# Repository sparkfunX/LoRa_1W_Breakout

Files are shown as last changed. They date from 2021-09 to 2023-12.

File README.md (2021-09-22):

SparkFun LoRa 1W Breakout
========================================

SparkFun LoRa 1W Breakout (https://www.sparkfun.com/products/18572)

[*SparkFun LoRa 1W Breakout (SPX-18572)*](https://www.sparkfun.com/products/18572)

Do you need power? This breakout for the 915M30S module from EBYTE is a 1W (30dB) LoRa transceiver. LoRa is great for long range long range (miles), low power (in sleep), and low data rates (~500bps). This breakout board is designed to connect to any platform that has SPI and 6 available GPIO. We include a robust edge mount RP-SMA connector to connect large LoRa (915MHz) antennas. In addition, the on-board U.FL connector can be used if you need to get outside a metal enclosure. 

We've successfully broadcast 12 miles line-of-sight (thank you [foothills](https://www.google.com/search?q=boulder+foothills&tbm=isch)!) using this module but your results may vary.

Our example sketches make quick work of the initial setup for the [SX1276 LoRa transceiver](https://www.semtech.com/products/wireless-rf/lora-core/sx1276) from Semtech, and the RadioLib Arduino Library makes advanced configuration and [protocols](https://github.com/jgromes/RadioLib/wiki/Default-configuration#protocols) (AX.25, Hellschreiber, Morse, RTTY, and SSTV) a cinch too!

Repository Contents
-------------------

* **/Documents** - Datasheets and mechanical drawings
* **/Hardware** - All Eagle design files (.brd, .sch, .STL)

Product Versions
----------------

* [SPX-18572](https://www.sparkfun.com/products/18572)

License Information
-------------------

This product is _**open source**_! 

Please review the LICENSE.md file for license information. 

If you have any questions or concerns on licensing, please contact technical support on our [SparkFun forums](https://forum.sparkfun.com/viewforum.php?f=152).

Distributed as-is; no warranty is given.

- Your friends at SparkFun.

_<COLLABORATION CREDIT>_

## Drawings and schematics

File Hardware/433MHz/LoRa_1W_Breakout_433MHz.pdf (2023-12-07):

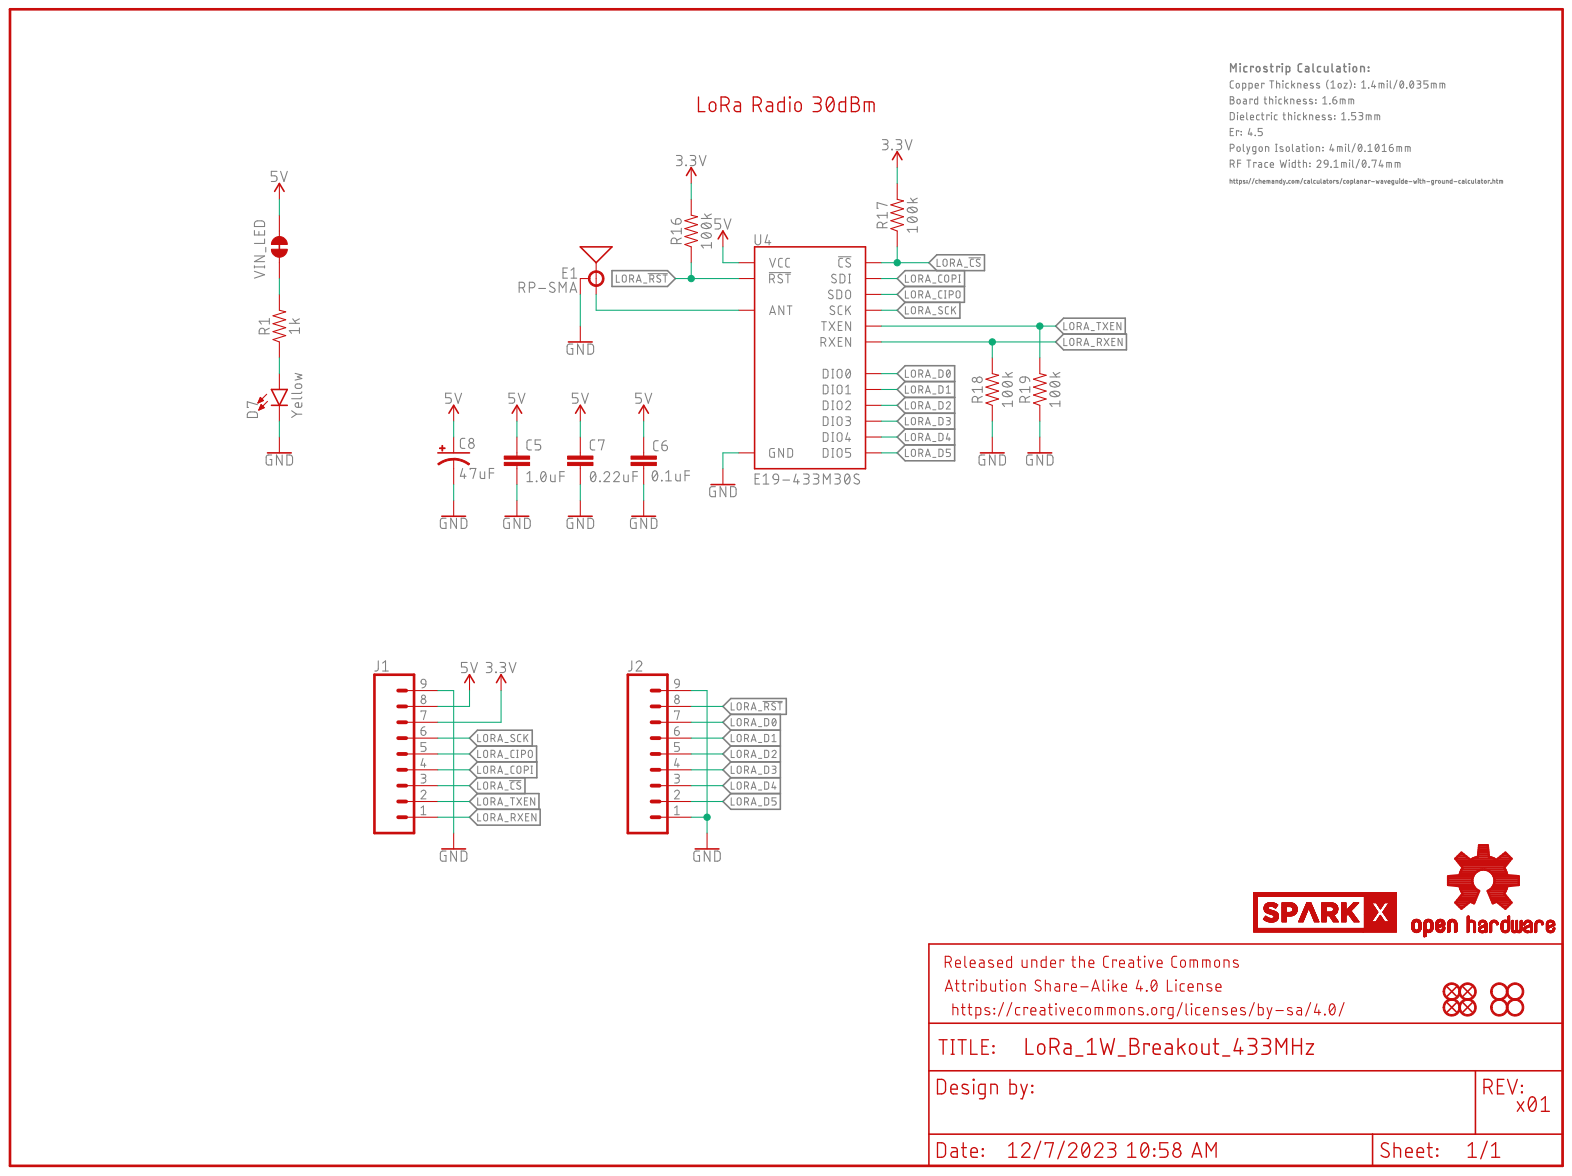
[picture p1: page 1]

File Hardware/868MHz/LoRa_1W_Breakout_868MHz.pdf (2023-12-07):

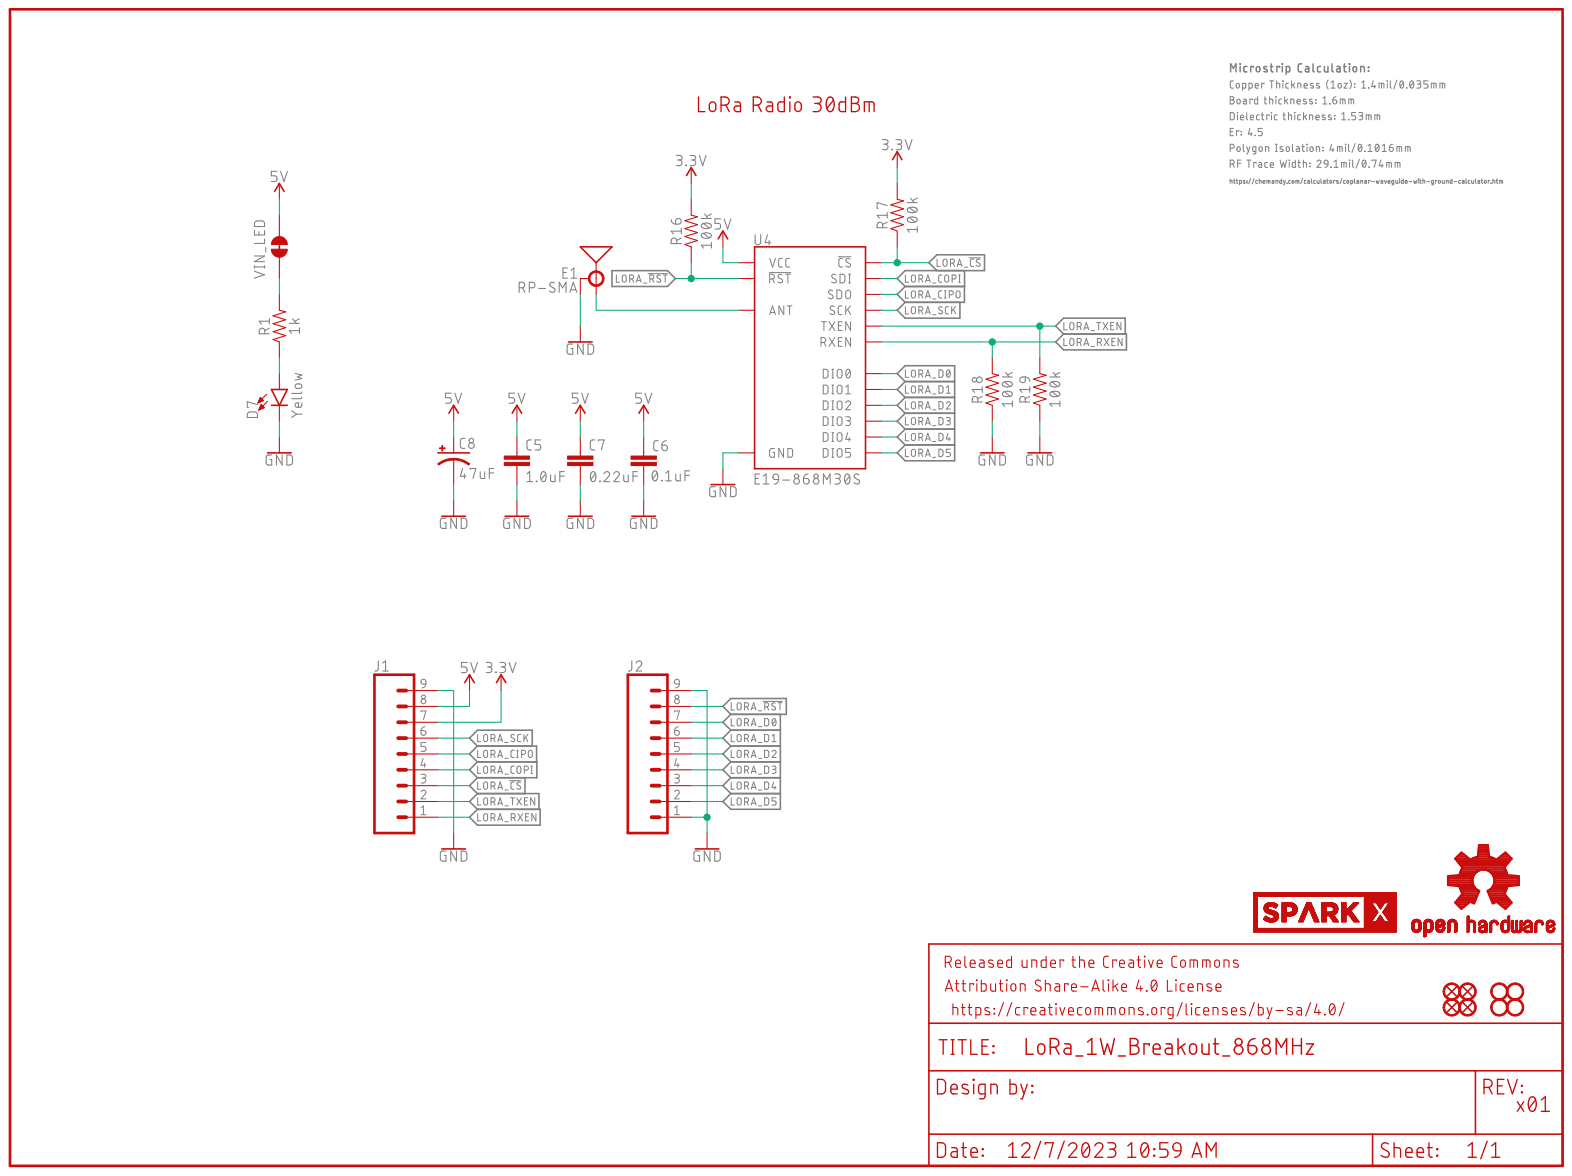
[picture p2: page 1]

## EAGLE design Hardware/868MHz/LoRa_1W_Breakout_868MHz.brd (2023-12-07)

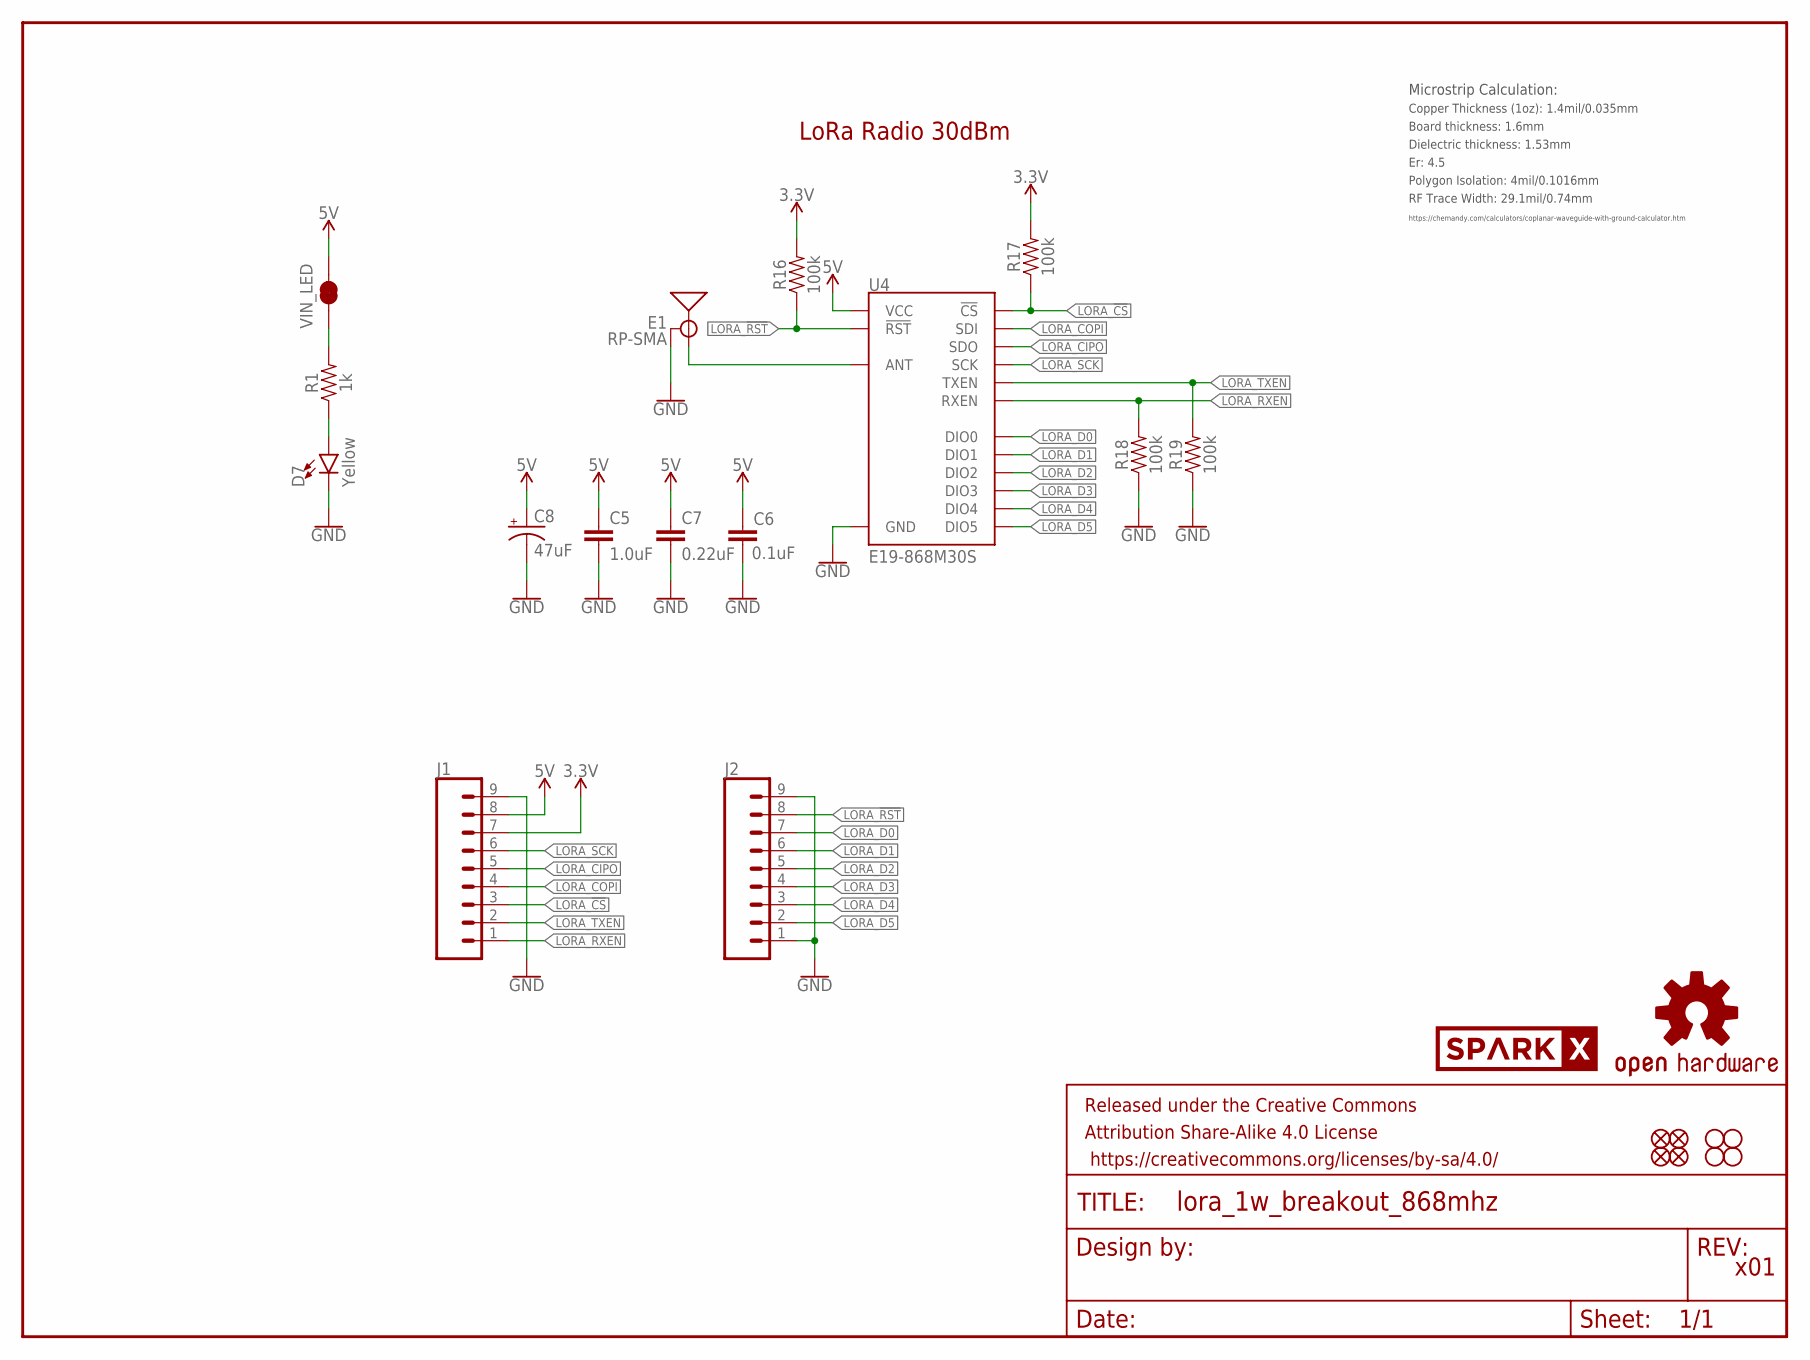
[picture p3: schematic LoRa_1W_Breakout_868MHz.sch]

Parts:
C5: 1.0uF; 0603
C6: 0.1uF; 0603
C7: 0.22uF; 0603
C8: 47uF; EIA3528
D7: Yellow; LED-0603
E1: RP-SMA; SMA-EDGE
FD1, FD2, FD3, FD4: FIDUCIALUFIDUCIAL; FIDUCIAL-MICRO
FRAME2: FRAME-LETTER; CREATIVE_COMMONS
H1, H2, H3, H4: STAND-OFF
J1, J2: CONN_09NO_SILK; 1X09_NO_SILK
LOGO3: OSHW-LOGOMINI; OSHW-LOGO-MINI
R1: 1k; 0603
R16, R17, R18, R19: 100k; 0603
U4: E19-868M30S; E19-915M30S
U$5: SPARKX-LOGO5; SPARKX-LARGE
VIN_LED: JUMPER-SMT_2_NC_TRACE_SILK; SMT-JUMPER_2_NC_TRACE_SILK

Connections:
3.3V: J1.7, R16.2, R17.2
5V: C5.1, C6.1, C7.1, C8.A (+), J1.8, U4.11 (VCC), VIN_LED.2
GND: C5.2, C6.2, C7.2, C8.C (-), D7.C, E1.GND@0 (GND), E1.GND@1 (GND), E1.GND@2 (GND), E1.GND@3 (GND), J1.9, J2.1, J2.9, R18.1, R19.1, U4.1 (GND), U4.9 (GND), U4.10 (GND), U4.18 (GND), U4.20 (GND), U4.21 (GND), U4.22 (GND)
LORA_!CS!: J1.3, R17.1, U4.15 (!CS)
LORA_!RST!: J2.8, R16.1, U4.8 (!RST)
LORA_CIPO: J1.5, U4.13 (SDO)
LORA_COPI: J1.4, U4.14 (SDI)
LORA_D0: J2.7, U4.7 (DIO0)
LORA_D1: J2.6, U4.6 (DIO1)
LORA_D2: J2.5, U4.5 (DIO2)
LORA_D3: J2.4, U4.4 (DIO3)
LORA_D4: J2.3, U4.3 (DIO4)
LORA_D5: J2.2, U4.2 (DIO5)
LORA_RF: E1.SIG (SIGNAL), U4.19 (ANT)
LORA_RXEN: J1.1, R18.2, U4.17 (RXEN)
LORA_SCK: J1.6, U4.12 (SCK)
LORA_TXEN: J1.2, R19.2, U4.16 (TXEN)
unnamed: R1.2, VIN_LED.1
unnamed: D7.A, R1.1

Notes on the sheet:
x01
LoRa Radio 30dBm
Board thickness: 1.6mm
Er: 4.5
Copper Thickness (1oz): 1.4mil/0.035mm
RF Trace Width: 29.1mil/0.74mm
Polygon Isolation: 4mil/0.1016mm
Dielectric thickness: 1.53mm
https://chemandy.com/calculators/coplanar-waveguide-with-ground-calculator.htm
Microstrip Calculation:

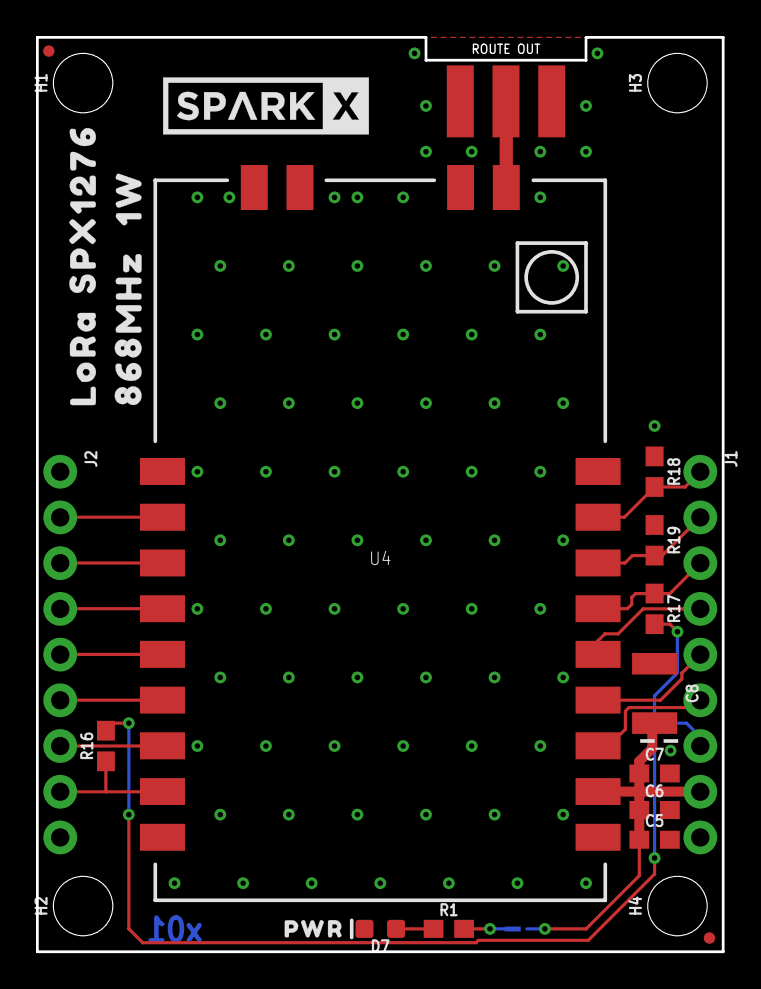
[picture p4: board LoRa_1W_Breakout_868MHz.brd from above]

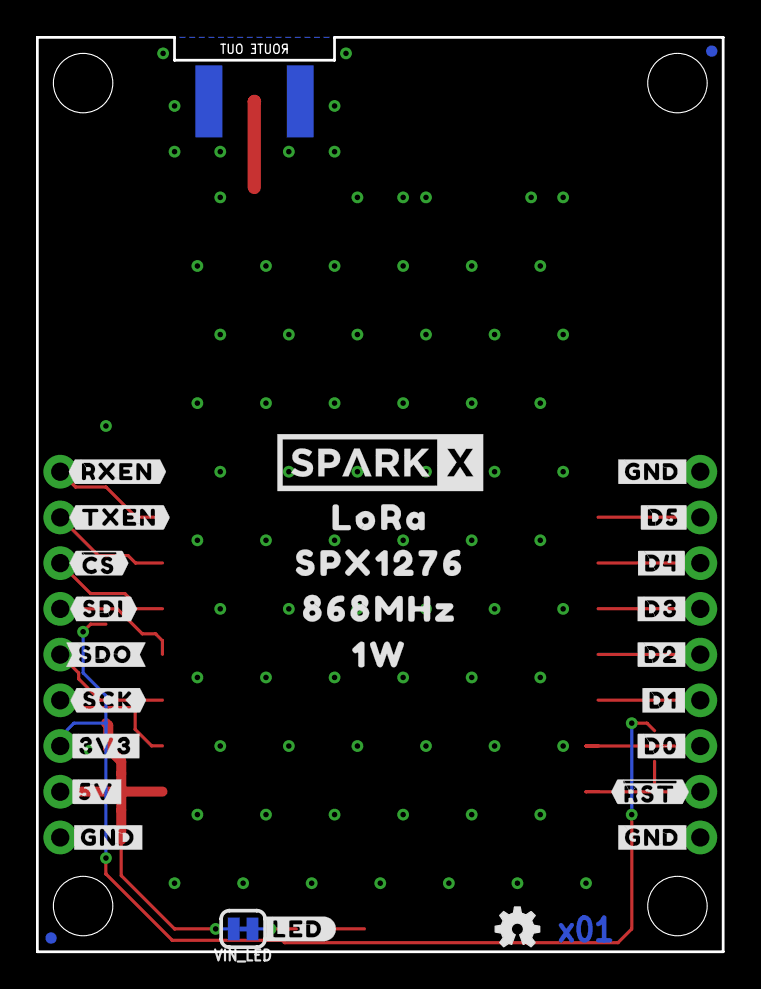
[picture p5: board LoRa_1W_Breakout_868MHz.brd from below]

Board: 2 copper layers, 38.1 x 50.8 mm, 55 parts (28 on the bottom side), 19 nets.

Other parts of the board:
U$1, U$67: LORA0
U$2, U$69: SPX12760
U$3, U$27: 1W1
U$4: PWR0
U$6: SPARKX-LOGO5; SPARKX-LARGE
U$7, U$9: 868MHZ0
U$15: #LED#0
U$43: #5V#1
U$44: #3V3#0
U$45: #SDO#3
U$46: #SDI#4
U$47: ##CS##5
U$48: #TXEN#6
U$49: #RXEN#7
U$52, U$53, U$61: #GND#8
U$54: #D5#6
U$55: #D4#5
U$56: #D3#4
U$57: #D2#3
U$58: #D1#2
U$59: #D0#1
U$60: ##RST##0
U$62: #SCK#2

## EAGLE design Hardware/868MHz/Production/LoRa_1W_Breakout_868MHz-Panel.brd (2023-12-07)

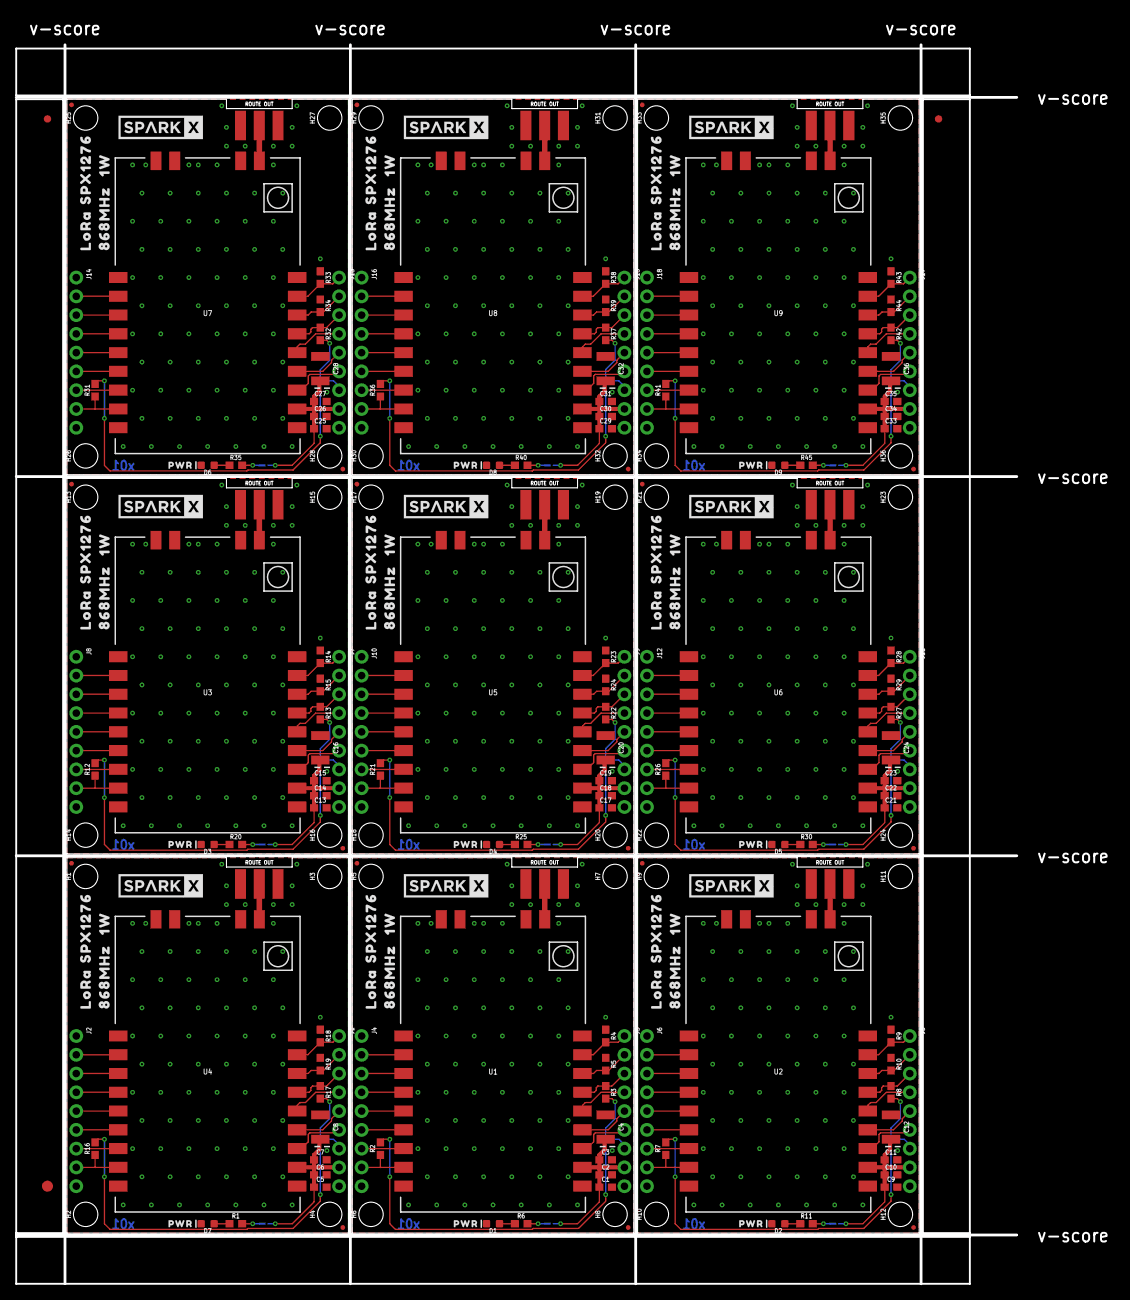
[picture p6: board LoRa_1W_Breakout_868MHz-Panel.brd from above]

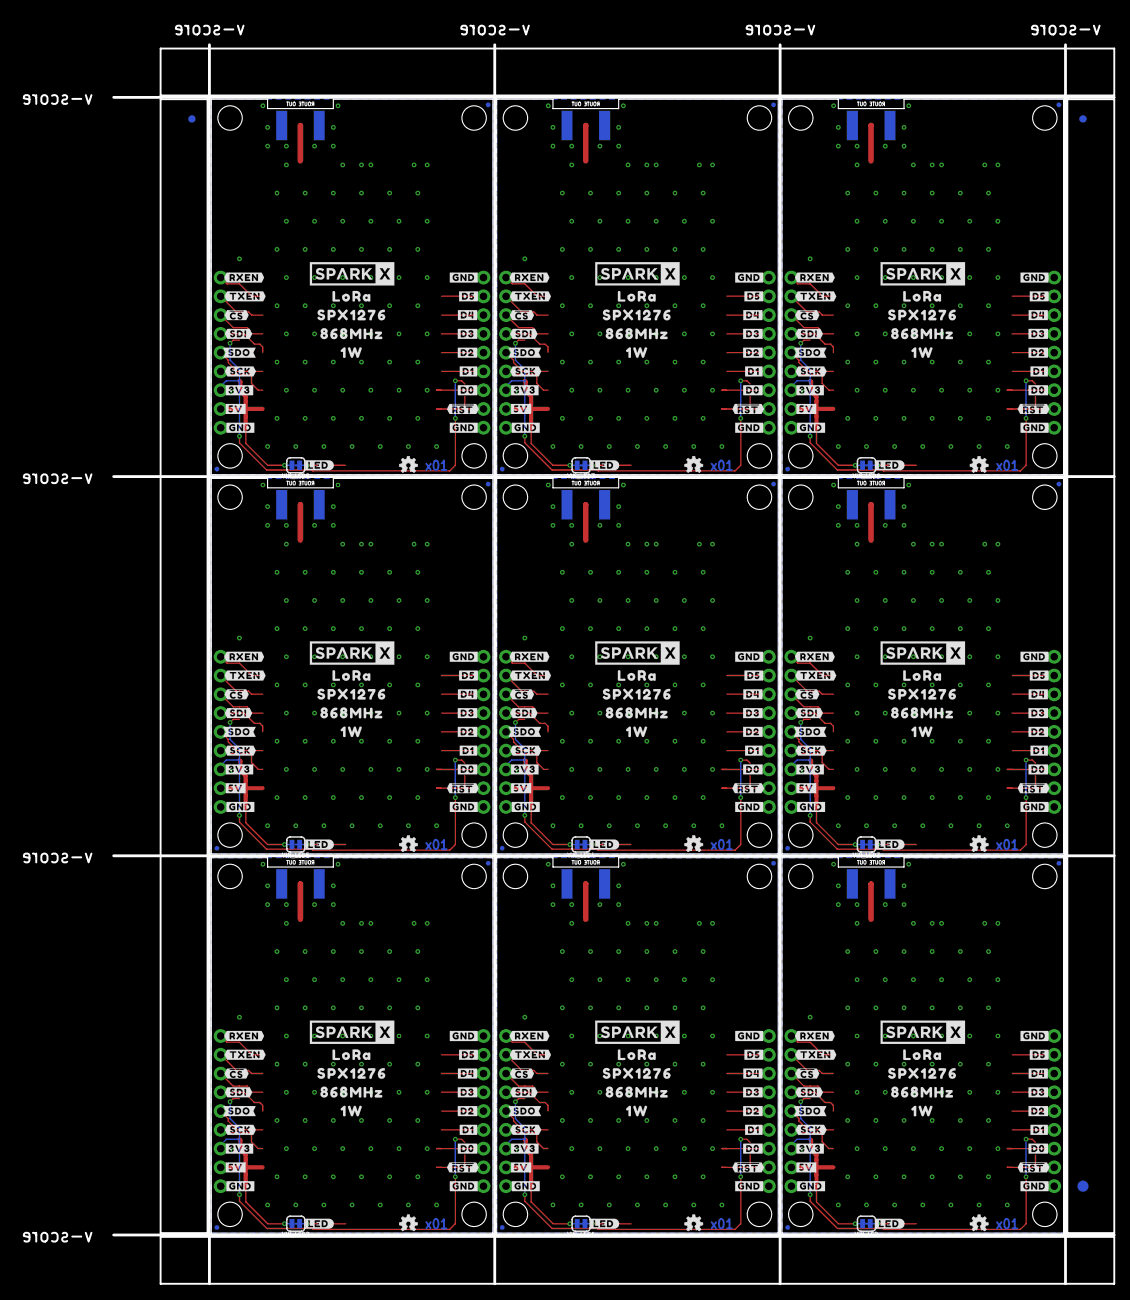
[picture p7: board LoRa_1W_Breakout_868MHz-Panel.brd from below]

Board: 2 copper layers, 135.4 x 167.6 mm, 492 parts (255 on the bottom side), 171 nets.

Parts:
C1, C5, C9, C13, C17, C21, C25, C29, C33: 1.0uF; 0603
C2, C6, C10, C14, C18, C22, C26, C30, C34: 0.1uF; 0603
C3, C7, C11, C15, C19, C23, C27, C31, C35: 0.22uF; 0603
C4, C8, C12, C16, C20, C24, C28, C32, C36: 47uF; EIA3528
D1, D2, D3, D4, D5, D6, D7, D8, D9: Yellow; LED-0603
E1, E2, E3, E4, E5, E6, E7, E8, E9: RP-SMA; SMA-EDGE
E$1, E$2, E$3, E$4: FIDUCIAL-1X2
E$5, E$6: FIDUCIAL-1.5X3
FD1, FD2, FD3, FD4, FD5, FD6, FD7, FD8, FD9, FD10, FD11, FD12, FD13, FD14, FD15, FD16, FD17, FD18, FD19, FD20, FD21, FD22, FD23, FD24, FD25, FD26, FD27, FD28, FD29, FD30, FD31, FD32, FD33, FD34, FD35, FD36: FIDUCIALUFIDUCIAL; FIDUCIAL-MICRO
H1, H2, H3, H4, H5, H6, H7, H8, H9, H10, H11, H12, H13, H14, H15, H16, H17, H18, H19, H20, H21, H22, H23, H24, H25, H26, H27, H28, H29, H30, H31, H32, H33, H34, H35, H36: STAND-OFF
J1, J2, J3, J4, J5, J6, J7, J8, J9, J10, J11, J12, J13, J14, J15, J16, J17, J18: 1X09_NO_SILK
LOGO1, LOGO2, LOGO3, LOGO4, LOGO5, LOGO6, LOGO7, LOGO8, LOGO9: OSHW-LOGOMINI; OSHW-LOGO-MINI
R1, R6, R11, R20, R25, R30, R35, R40, R45: 1k; 0603
R2, R3, R4, R5, R7, R8, R9, R10, R12, R13, R14, R15, R16, R17, R18, R19, R21, R22, R23, R24, R26, R27, R28, R29, R31, R32, R33, R34, R36, R37, R38, R39, R41, R42, R43, R44: 100k; 0603
U1, U2, U3, U4, U5, U6, U7, U8, U9: E19-915M30S
U$1, U$32, U$34, U$67, U$82, U$84, U$112, U$114, U$142, U$144, U$172, U$174, U$202, U$204, U$232, U$234, U$262, U$264: LORA0
U$2, U$33, U$35, U$69, U$83, U$85, U$113, U$115, U$143, U$145, U$173, U$175, U$203, U$205, U$233, U$235, U$263, U$265: SPX12760
U$3, U$27, U$31, U$36, U$81, U$86, U$111, U$116, U$141, U$146, U$171, U$176, U$201, U$206, U$231, U$236, U$261, U$266: 1W1
U$4, U$8, U$41, U$91, U$121, U$151, U$181, U$211, U$241: PWR0
U$5, U$6, U$37, U$38, U$87, U$88, U$117, U$118, U$147, U$148, U$177, U$178, U$207, U$208, U$237, U$238, U$267, U$268: SPARKX-LOGO5; SPARKX-LARGE
U$7, U$9, U$39, U$40, U$89, U$90, U$119, U$120, U$149, U$150, U$179, U$180, U$209, U$210, U$239, U$240, U$269, U$270: 868MHZ0
U$10, U$15, U$42, U$92, U$122, U$152, U$182, U$212, U$242: #LED#0
U$11, U$43, U$50, U$93, U$123, U$153, U$183, U$213, U$243: #5V#1
U$12, U$44, U$51, U$94, U$124, U$154, U$184, U$214, U$244: #3V3#0
U$13, U$45, U$63, U$95, U$125, U$155, U$185, U$215, U$245: #SDO#3
U$14, U$46, U$64, U$96, U$126, U$156, U$186, U$216, U$246: #SDI#4
U$16, U$47, U$65, U$97, U$127, U$157, U$187, U$217, U$247: ##CS##5
U$17, U$48, U$66, U$98, U$128, U$158, U$188, U$218, U$248: #TXEN#6
U$18, U$49, U$68, U$99, U$129, U$159, U$189, U$219, U$249: #RXEN#7
U$19, U$20, U$29, U$52, U$53, U$61, U$70, U$71, U$79, U$100, U$101, U$109, U$130, U$131, U$139, U$160, U$161, U$169, U$190, U$191, U$199, U$220, U$221, U$229, U$250, U$251, U$259: #GND#8
U$21, U$54, U$72, U$102, U$132, U$162, U$192, U$222, U$252: #D5#6
U$22, U$55, U$73, U$103, U$133, U$163, U$193, U$223, U$253: #D4#5
U$23, U$56, U$74, U$104, U$134, U$164, U$194, U$224, U$254: #D3#4
U$24, U$57, U$75, U$105, U$135, U$165, U$195, U$225, U$255: #D2#3
U$25, U$58, U$76, U$106, U$136, U$166, U$196, U$226, U$256: #D1#2
U$26, U$59, U$77, U$107, U$137, U$167, U$197, U$227, U$257: #D0#1
U$28, U$60, U$78, U$108, U$138, U$168, U$198, U$228, U$258: ##RST##0
U$30, U$62, U$80, U$110, U$140, U$170, U$200, U$230, U$260: #SCK#2
VIN_LED, VIN_LED1, VIN_LED2, VIN_LED3, VIN_LED4, VIN_LED5, VIN_LED6, VIN_LED7, VIN_LED8: JUMPER-SMT_2_NC_TRACE_SILK; SMT-JUMPER_2_NC_TRACE_SILK

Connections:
3.3V: J1.7, R16.2, R17.2
3.3V1: J3.7, R2.2, R3.2
3.3V2: J5.7, R7.2, R8.2
3.3V3: J7.7, R12.2, R13.2
3.3V4: J9.7, R21.2, R22.2
3.3V5: J11.7, R26.2, R27.2
3.3V6: J13.7, R31.2, R32.2
3.3V7: J15.7, R36.2, R37.2
3.3V8: J17.7, R41.2, R42.2
5V: C5.1, C6.1, C7.1, C8.A, J1.8, U4.11, VIN_LED.2
5V1: C1.1, C2.1, C3.1, C4.A, J3.8, U1.11, VIN_LED1.2
5V2: C9.1, C10.1, C11.1, C12.A, J5.8, U2.11, VIN_LED2.2
5V3: C13.1, C14.1, C15.1, C16.A, J7.8, U3.11, VIN_LED3.2
5V4: C17.1, C18.1, C19.1, C20.A, J9.8, U5.11, VIN_LED4.2
5V5: C21.1, C22.1, C23.1, C24.A, J11.8, U6.11, VIN_LED5.2
5V6: C25.1, C26.1, C27.1, C28.A, J13.8, U7.11, VIN_LED6.2
5V7: C29.1, C30.1, C31.1, C32.A, J15.8, U8.11, VIN_LED7.2
5V8: C33.1, C34.1, C35.1, C36.A, J17.8, U9.11, VIN_LED8.2
GND: C5.2, C6.2, C7.2, C8.C, D7.C, E1.GND@0, E1.GND@1, E1.GND@2, E1.GND@3, J1.9, J2.1, J2.9, R18.1, R19.1, U4.1, U4.9, U4.10, U4.18, U4.20, U4.21, U4.22
GND1: C1.2, C2.2, C3.2, C4.C, D1.C, E2.GND@0, E2.GND@1, E2.GND@2, E2.GND@3, J3.9, J4.1, J4.9, R4.1, R5.1, U1.1, U1.9, U1.10, U1.18, U1.20, U1.21, U1.22
GND2: C9.2, C10.2, C11.2, C12.C, D2.C, E3.GND@0, E3.GND@1, E3.GND@2, E3.GND@3, J5.9, J6.1, J6.9, R9.1, R10.1, U2.1, U2.9, U2.10, U2.18, U2.20, U2.21, U2.22
GND3: C13.2, C14.2, C15.2, C16.C, D3.C, E4.GND@0, E4.GND@1, E4.GND@2, E4.GND@3, J7.9, J8.1, J8.9, R14.1, R15.1, U3.1, U3.9, U3.10, U3.18, U3.20, U3.21, U3.22
GND4: C17.2, C18.2, C19.2, C20.C, D4.C, E5.GND@0, E5.GND@1, E5.GND@2, E5.GND@3, J9.9, J10.1, J10.9, R23.1, R24.1, U5.1, U5.9, U5.10, U5.18, U5.20, U5.21, U5.22
GND5: C21.2, C22.2, C23.2, C24.C, D5.C, E6.GND@0, E6.GND@1, E6.GND@2, E6.GND@3, J11.9, J12.1, J12.9, R28.1, R29.1, U6.1, U6.9, U6.10, U6.18, U6.20, U6.21, U6.22
GND6: C25.2, C26.2, C27.2, C28.C, D6.C, E7.GND@0, E7.GND@1, E7.GND@2, E7.GND@3, J13.9, J14.1, J14.9, R33.1, R34.1, U7.1, U7.9, U7.10, U7.18, U7.20, U7.21, U7.22
GND7: C29.2, C30.2, C31.2, C32.C, D8.C, E8.GND@0, E8.GND@1, E8.GND@2, E8.GND@3, J15.9, J16.1, J16.9, R38.1, R39.1, U8.1, U8.9, U8.10, U8.18, U8.20, U8.21, U8.22
GND8: C33.2, C34.2, C35.2, C36.C, D9.C, E9.GND@0, E9.GND@1, E9.GND@2, E9.GND@3, J17.9, J18.1, J18.9, R43.1, R44.1, U9.1, U9.9, U9.10, U9.18, U9.20, U9.21, U9.22
LORA_!CS!: J1.3, R17.1, U4.15
LORA_!CS!1: J3.3, R3.1, U1.15
LORA_!CS!2: J5.3, R8.1, U2.15
LORA_!CS!3: J7.3, R13.1, U3.15
LORA_!CS!4: J9.3, R22.1, U5.15
LORA_!CS!5: J11.3, R27.1, U6.15
LORA_!CS!6: J13.3, R32.1, U7.15
LORA_!CS!7: J15.3, R37.1, U8.15
LORA_!CS!8: J17.3, R42.1, U9.15
LORA_!RST!: J2.8, R16.1, U4.8
LORA_!RST!1: J4.8, R2.1, U1.8
LORA_!RST!2: J6.8, R7.1, U2.8
LORA_!RST!3: J8.8, R12.1, U3.8
LORA_!RST!4: J10.8, R21.1, U5.8
LORA_!RST!5: J12.8, R26.1, U6.8
LORA_!RST!6: J14.8, R31.1, U7.8
LORA_!RST!7: J16.8, R36.1, U8.8
LORA_!RST!8: J18.8, R41.1, U9.8
LORA_CIPO: J1.5, U4.13
LORA_CIPO1: J3.5, U1.13
LORA_CIPO2: J5.5, U2.13
LORA_CIPO3: J7.5, U3.13
LORA_CIPO4: J9.5, U5.13
LORA_CIPO5: J11.5, U6.13
LORA_CIPO6: J13.5, U7.13
LORA_CIPO7: J15.5, U8.13
LORA_CIPO8: J17.5, U9.13
LORA_COPI: J1.4, U4.14
LORA_COPI1: J3.4, U1.14
LORA_COPI2: J5.4, U2.14
LORA_COPI3: J7.4, U3.14
LORA_COPI4: J9.4, U5.14
LORA_COPI5: J11.4, U6.14
LORA_COPI6: J13.4, U7.14
LORA_COPI7: J15.4, U8.14
LORA_COPI8: J17.4, U9.14
LORA_D0: J2.7, U4.7
LORA_D1: J2.6, U4.6
LORA_D2: J2.5, U4.5
LORA_D3: J2.4, U4.4
LORA_D4: J2.3, U4.3
LORA_D5: J2.2, U4.2
LORA_D6: J4.7, U1.7
LORA_D7: J4.6, U1.6
LORA_D8: J4.5, U1.5
LORA_D9: J4.4, U1.4
LORA_D10: J4.3, U1.3
LORA_D11: J4.2, U1.2
LORA_D12: J6.7, U2.7
LORA_D13: J6.6, U2.6
LORA_D14: J6.5, U2.5
LORA_D15: J6.4, U2.4
LORA_D16: J6.3, U2.3
LORA_D17: J6.2, U2.2
LORA_D18: J8.7, U3.7
LORA_D19: J8.6, U3.6
LORA_D20: J8.5, U3.5
LORA_D21: J8.4, U3.4
LORA_D22: J8.3, U3.3
LORA_D23: J8.2, U3.2
LORA_D24: J10.7, U5.7
LORA_D25: J10.6, U5.6
LORA_D26: J10.5, U5.5
LORA_D27: J10.4, U5.4
LORA_D28: J10.3, U5.3
LORA_D29: J10.2, U5.2
LORA_D30: J12.7, U6.7
LORA_D31: J12.6, U6.6
LORA_D32: J12.5, U6.5
LORA_D33: J12.4, U6.4
LORA_D34: J12.3, U6.3
LORA_D35: J12.2, U6.2
LORA_D36: J14.7, U7.7
LORA_D37: J14.6, U7.6
LORA_D38: J14.5, U7.5
LORA_D39: J14.4, U7.4
LORA_D40: J14.3, U7.3
LORA_D41: J14.2, U7.2
LORA_D42: J16.7, U8.7
LORA_D43: J16.6, U8.6
LORA_D44: J16.5, U8.5
LORA_D45: J16.4, U8.4
LORA_D46: J16.3, U8.3
LORA_D47: J16.2, U8.2
LORA_D48: J18.7, U9.7
LORA_D49: J18.6, U9.6
LORA_D50: J18.5, U9.5
LORA_D51: J18.4, U9.4
LORA_D52: J18.3, U9.3
LORA_D53: J18.2, U9.2
LORA_RF: E1.SIG, U4.19
LORA_RF1: E2.SIG, U1.19
LORA_RF2: E3.SIG, U2.19
LORA_RF3: E4.SIG, U3.19
LORA_RF4: E5.SIG, U5.19
LORA_RF5: E6.SIG, U6.19
LORA_RF6: E7.SIG, U7.19
LORA_RF7: E8.SIG, U8.19
LORA_RF8: E9.SIG, U9.19
LORA_RXEN: J1.1, R18.2, U4.17
LORA_RXEN1: J3.1, R4.2, U1.17
LORA_RXEN2: J5.1, R9.2, U2.17
LORA_RXEN3: J7.1, R14.2, U3.17
LORA_RXEN4: J9.1, R23.2, U5.17
LORA_RXEN5: J11.1, R28.2, U6.17
LORA_RXEN6: J13.1, R33.2, U7.17
LORA_RXEN7: J15.1, R38.2, U8.17
LORA_RXEN8: J17.1, R43.2, U9.17
LORA_SCK: J1.6, U4.12
LORA_SCK1: J3.6, U1.12
LORA_SCK2: J5.6, U2.12
LORA_SCK3: J7.6, U3.12
LORA_SCK4: J9.6, U5.12
LORA_SCK5: J11.6, U6.12
LORA_SCK6: J13.6, U7.12
LORA_SCK7: J15.6, U8.12
LORA_SCK8: J17.6, U9.12
LORA_TXEN: J1.2, R19.2, U4.16
LORA_TXEN1: J3.2, R5.2, U1.16
LORA_TXEN2: J5.2, R10.2, U2.16
LORA_TXEN3: J7.2, R15.2, U3.16
LORA_TXEN4: J9.2, R24.2, U5.16
LORA_TXEN5: J11.2, R29.2, U6.16
LORA_TXEN6: J13.2, R34.2, U7.16
LORA_TXEN7: J15.2, R39.2, U8.16
LORA_TXEN8: J17.2, R44.2, U9.16
unnamed: R6.2, VIN_LED1.1
unnamed: D1.A, R6.1
unnamed: R11.2, VIN_LED2.1
unnamed: D2.A, R11.1
unnamed: R20.2, VIN_LED3.1
unnamed: D3.A, R20.1
unnamed: R25.2, VIN_LED4.1
unnamed: R1.2, VIN_LED.1
unnamed: D7.A, R1.1
unnamed: D4.A, R25.1
unnamed: R30.2, VIN_LED5.1
unnamed: D5.A, R30.1
unnamed: R35.2, VIN_LED6.1
unnamed: D6.A, R35.1
unnamed: R40.2, VIN_LED7.1
unnamed: D8.A, R40.1
unnamed: R45.2, VIN_LED8.1
unnamed: D9.A, R45.1

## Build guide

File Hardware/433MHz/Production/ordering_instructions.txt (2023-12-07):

panel size, 130x160mm
PCB thickness, 1.6mm
number of layers, 2
soldermask color, Black
silkscreen color, White
oz copper, 1oz
finish, HASL lead free
stencils, none
pcs per panel, 9
min trace width, 0.1778mm / 0.0070in
min drill size, 0.3048mm / 0.0120in

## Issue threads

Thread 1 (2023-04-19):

LoRa Module Error -2

Robocoder9000, 2023-04-19:
I've hooked up the transceiver to an Arduino Nano and a Sparkfun Redboard, with all SPI, ground, 3.3v, and 5v pins hooked up as well as d0 on a hardware reset pin and d1 on a digital pin. I was using 3.3v logic on the Redboard, and had 1k resistors on the Nano's logic lines as suggested under the product page by Nate. However, on both boards when I run the example code, I always get the same "Initializing ... failed, code -2" error. Am I missing anything? I've tried using the provided code as well as the example code from Radiolib, and the issue persists. What else could I try?

Robocoder9000, 2023-05-04:
Ah, turns out my SDI and SDO pins were backwards.

PaulZC, 2023-05-04:
Thanks for the update - glad that's working for you

Robocoder9000, 2023-05-05:
Thanks! Quick question for you- I'm looking to boost the range of the system, I'm only getting around 500m as of now. Are there any software tricks I can try? I'm already at 20dbm boost power.

Closed 2023-05-04.

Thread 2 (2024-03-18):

Ordering A Board

agieocean, 2024-03-18:
I'm a bit new to open hardware so excuse the question but is the intention that I solder the components to the board myself or is there some info in this repo I could provide a fabricator so they know which components to order/where to put them on the board?

nseidle, 2024-03-18:
You can either order an assembled/tested board from [us](https://www.sparkfun.com/products/18572) or you can have your own PCB made, and assemble one yourself. The goal of making the design open was so that others could start from 'known working' design.

agieocean, 2024-03-18:
Thank you so much for your response.

Closed 2024-03-18.

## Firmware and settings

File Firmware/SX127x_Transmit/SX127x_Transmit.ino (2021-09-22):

/*
  RadioLib SX1276 Transmit Example using the 1W LoRa Module @ 915MHz

  Gotchas:
      The RadioLib defaults the SX1276 to 434MHz so the reception is pretty
      poor. This is fixed with a radio.begin(915.0);
      The RadioLib really requires DIO0 and DIO1 be connected. Reset is optional.
      Avoid ESP pins 34/35/36/39 as they are inputs only
*/

#include <RadioLib.h> //Click here to get the library: http://librarymanager/All#RadioLib

// SX1276 requires the following connections:
int pin_cs = 41;
int pin_dio0 = 0;
int pin_nrst = 33;
int pin_dio1 = 34;
SX1276 radio = new Module(pin_cs, pin_dio0, pin_nrst, pin_dio1);

void setup() {
  Serial.begin(115200);
  delay(500); //Wait for ESP32 to be able to print

  Serial.print(F("[SX1276] Initializing ... "));
  //int state = radio.begin(); //-121dBm
  //int state = radio.begin(868.0); //-20dBm
  int state = radio.begin(915.0); //-23dBm
  if (state == ERR_NONE) {
    Serial.println(F("init success!"));
  } else {
    Serial.print(F("failed, code "));
    Serial.println(state);
    while (true);
  }

  // set output power to 10 dBm (accepted range is -3 - 17 dBm)
  // NOTE: 20 dBm value allows high power operation, but transmission
  //       duty cycle MUST NOT exceed 1%
//  if (radio.setOutputPower(20) == ERR_INVALID_OUTPUT_POWER) {
//    Serial.println(F("Selected output power is invalid for this module!"));
//    while (true);
//  }

  // some modules have an external RF switch
  // controlled via two pins (RX enable, TX enable)
  // to enable automatic control of the switch,
  // call the following method
  int pin_rx_enable = 16;
  int pin_tx_enable = 44;
  radio.setRfSwitchPins(pin_rx_enable, pin_tx_enable);
}

int counter = 0;

void loop() {
  Serial.print(F("[SX1276] Transmitting packet ... "));

  // you can transmit C-string or Arduino string up to
  // 256 characters long
  // NOTE: transmit() is a blocking method!
  //       See example SX127x_Transmit_Interrupt for details
  //       on non-blocking transmission method.

  char output[50];
  sprintf(output, "Counter: %d", counter++);

  int state = radio.transmit(output);

  // you can also transmit byte array up to 256 bytes long
  /*
    byte byteArr[] = {0x01, 0x23, 0x45, 0x67, 0x89, 0xAB, 0xCD, 0xEF};
    int state = radio.transmit(byteArr, 8);
  */

  if (state == ERR_NONE) {
    // the packet was successfully transmitted
    Serial.println(F(" success!"));

    // print measured data rate
    Serial.print(F("[SX1276] Datarate:\t"));
    Serial.print(radio.getDataRate());
    Serial.println(F(" bps"));

  } else if (state == ERR_PACKET_TOO_LONG) {
    // the supplied packet was longer than 256 bytes
    Serial.println(F("too long!"));

  } else if (state == ERR_TX_TIMEOUT) {
    // timeout occurred while transmitting packet
    Serial.println(F("timeout!"));

  } else {
    // some other error occurred
    Serial.print(F("failed, code "));
    Serial.println(state);
  }

  // wait for a second before transmitting again
  delay(1000);
}

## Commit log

2021-09-03 Update to x02
    [LoRa_1W_Breakout-Panel.GBL, LoRa_1W_Breakout-Panel.GBO, LoRa_1W_Breakout-Panel.GBP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]
2021-09-22 Remove backup files
    [LoRa_1W_Breakout.sch]
2023-12-07 Add 433 and 868
    [LoRa_1W_Breakout-Panel.GBL, LoRa_1W_Breakout-Panel.GBO, LoRa_1W_Breakout-Panel.GBP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]
2023-12-07 Update schematics
    [LoRa_1W_Breakout_433MHz.brd, LoRa_1W_Breakout_433MHz.sch, LoRa_1W_Breakout_868MHz.brd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]

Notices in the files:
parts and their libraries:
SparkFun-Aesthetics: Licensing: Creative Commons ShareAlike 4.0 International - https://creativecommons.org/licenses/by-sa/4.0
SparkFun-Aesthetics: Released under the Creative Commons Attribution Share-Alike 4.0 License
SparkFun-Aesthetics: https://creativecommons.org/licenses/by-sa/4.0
